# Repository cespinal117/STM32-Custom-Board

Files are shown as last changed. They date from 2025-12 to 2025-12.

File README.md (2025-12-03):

# STM32-Custom-Board

This is a board I decided to create to practice my PCB Design skills.  

I chose the STM32 as the main MCU due to me wanting to learn the STM32 platform.

My main motivation for the features of this board is that throughout college I mostly worked on projects involved Servo motors. Instead of having a separate Servo driver board with more wires, I thought it would be nice to have it all embedded into a single PCB that will power and control everything.  
The ESP32 was a last second addition as I thought it would be cool to be able to control the motors wirelessly through a web interface or bluetooth.

# Features
- STM32 MCU as the main processor
- ESP32 for wireless capabitlities
- PCA9685 Servo driver
- Switching between 5V USB or external 5V (prioritizes USB for the MCU if plugged in)

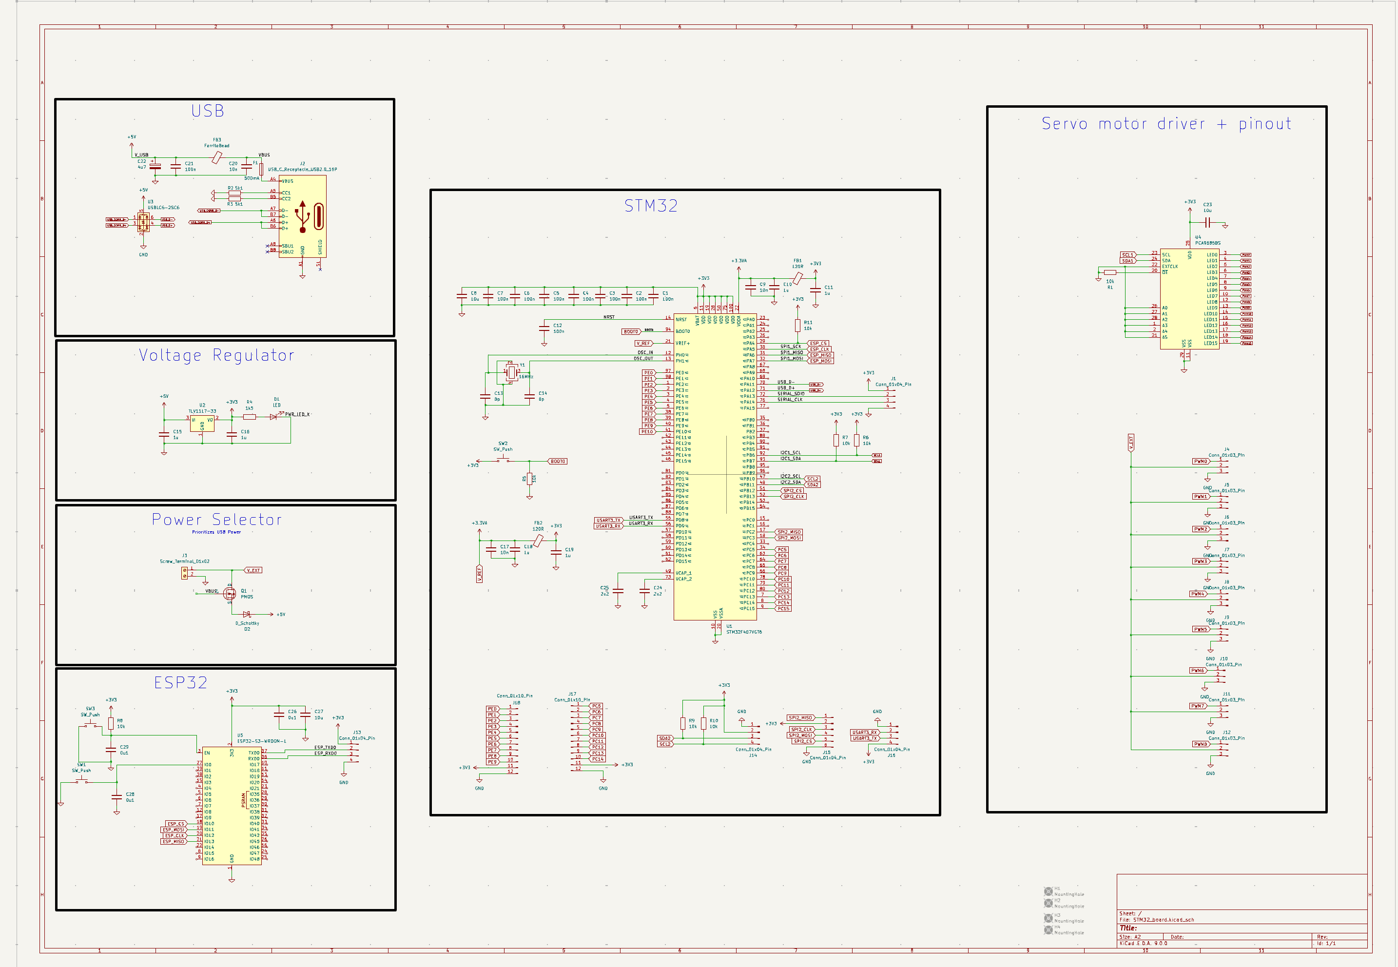
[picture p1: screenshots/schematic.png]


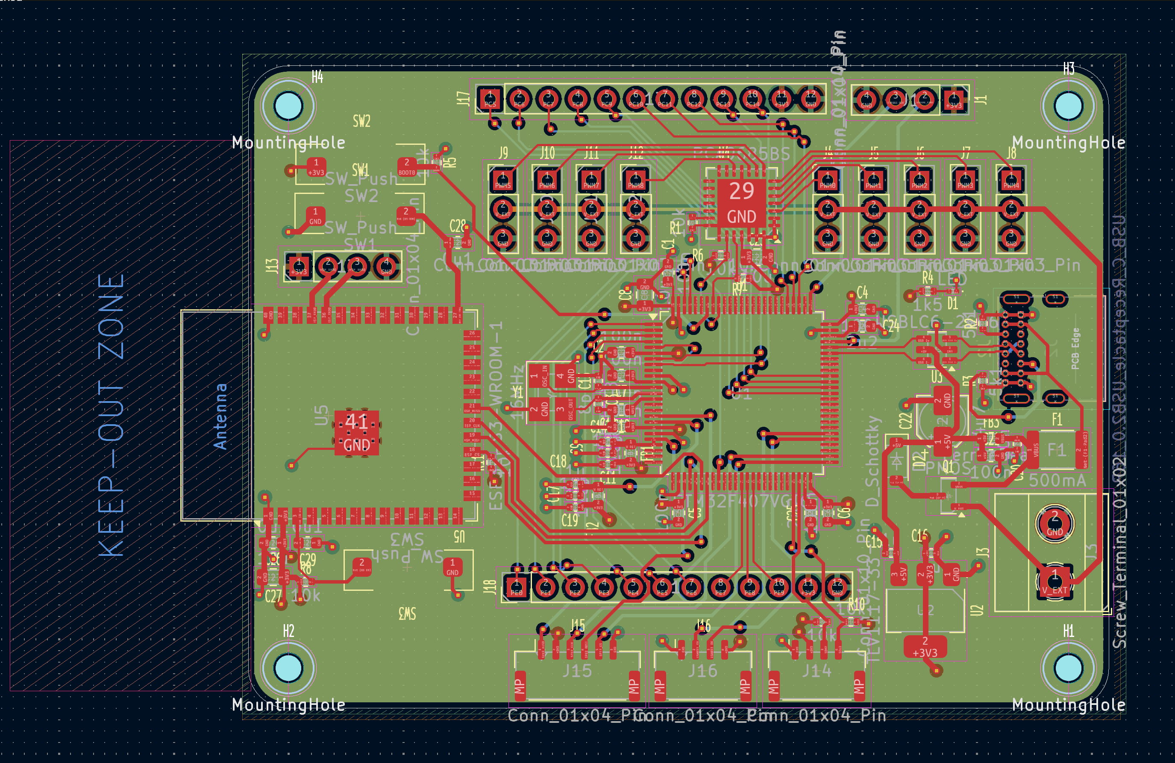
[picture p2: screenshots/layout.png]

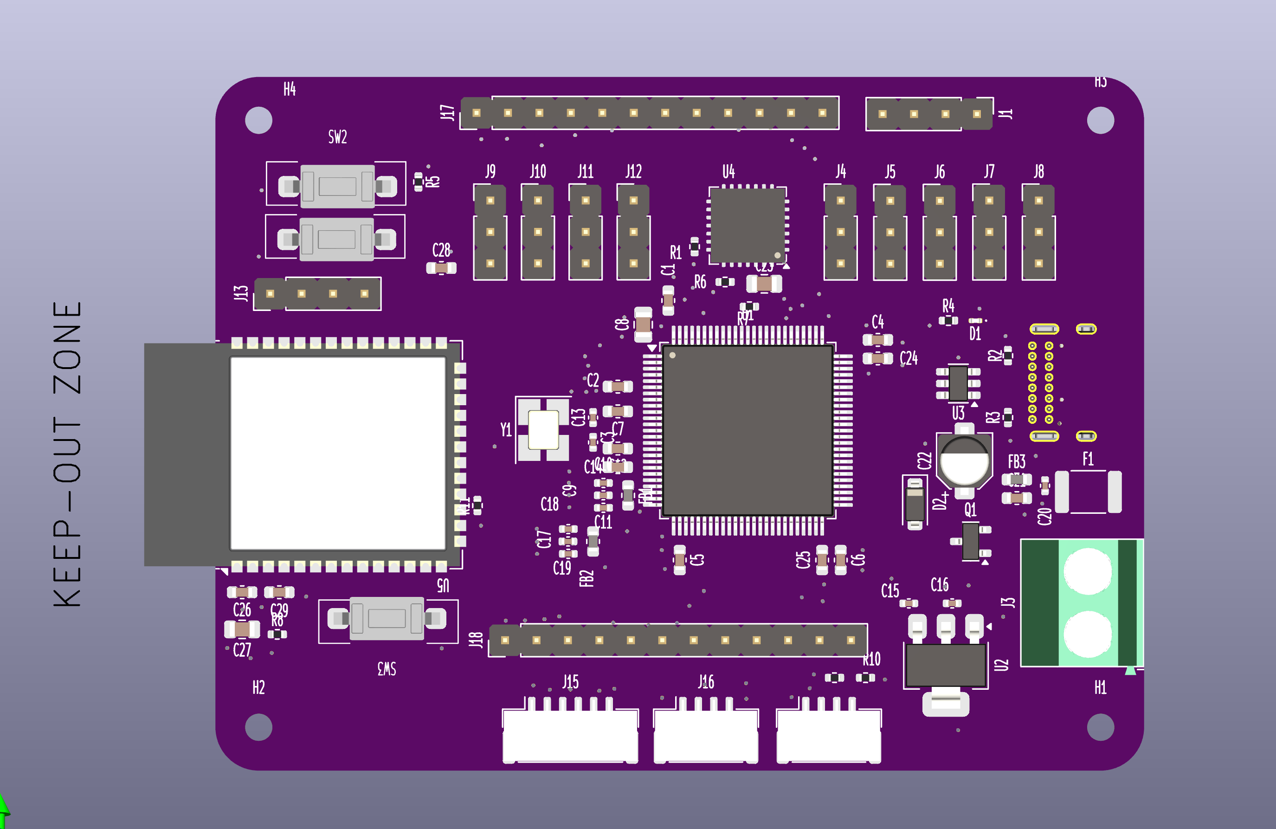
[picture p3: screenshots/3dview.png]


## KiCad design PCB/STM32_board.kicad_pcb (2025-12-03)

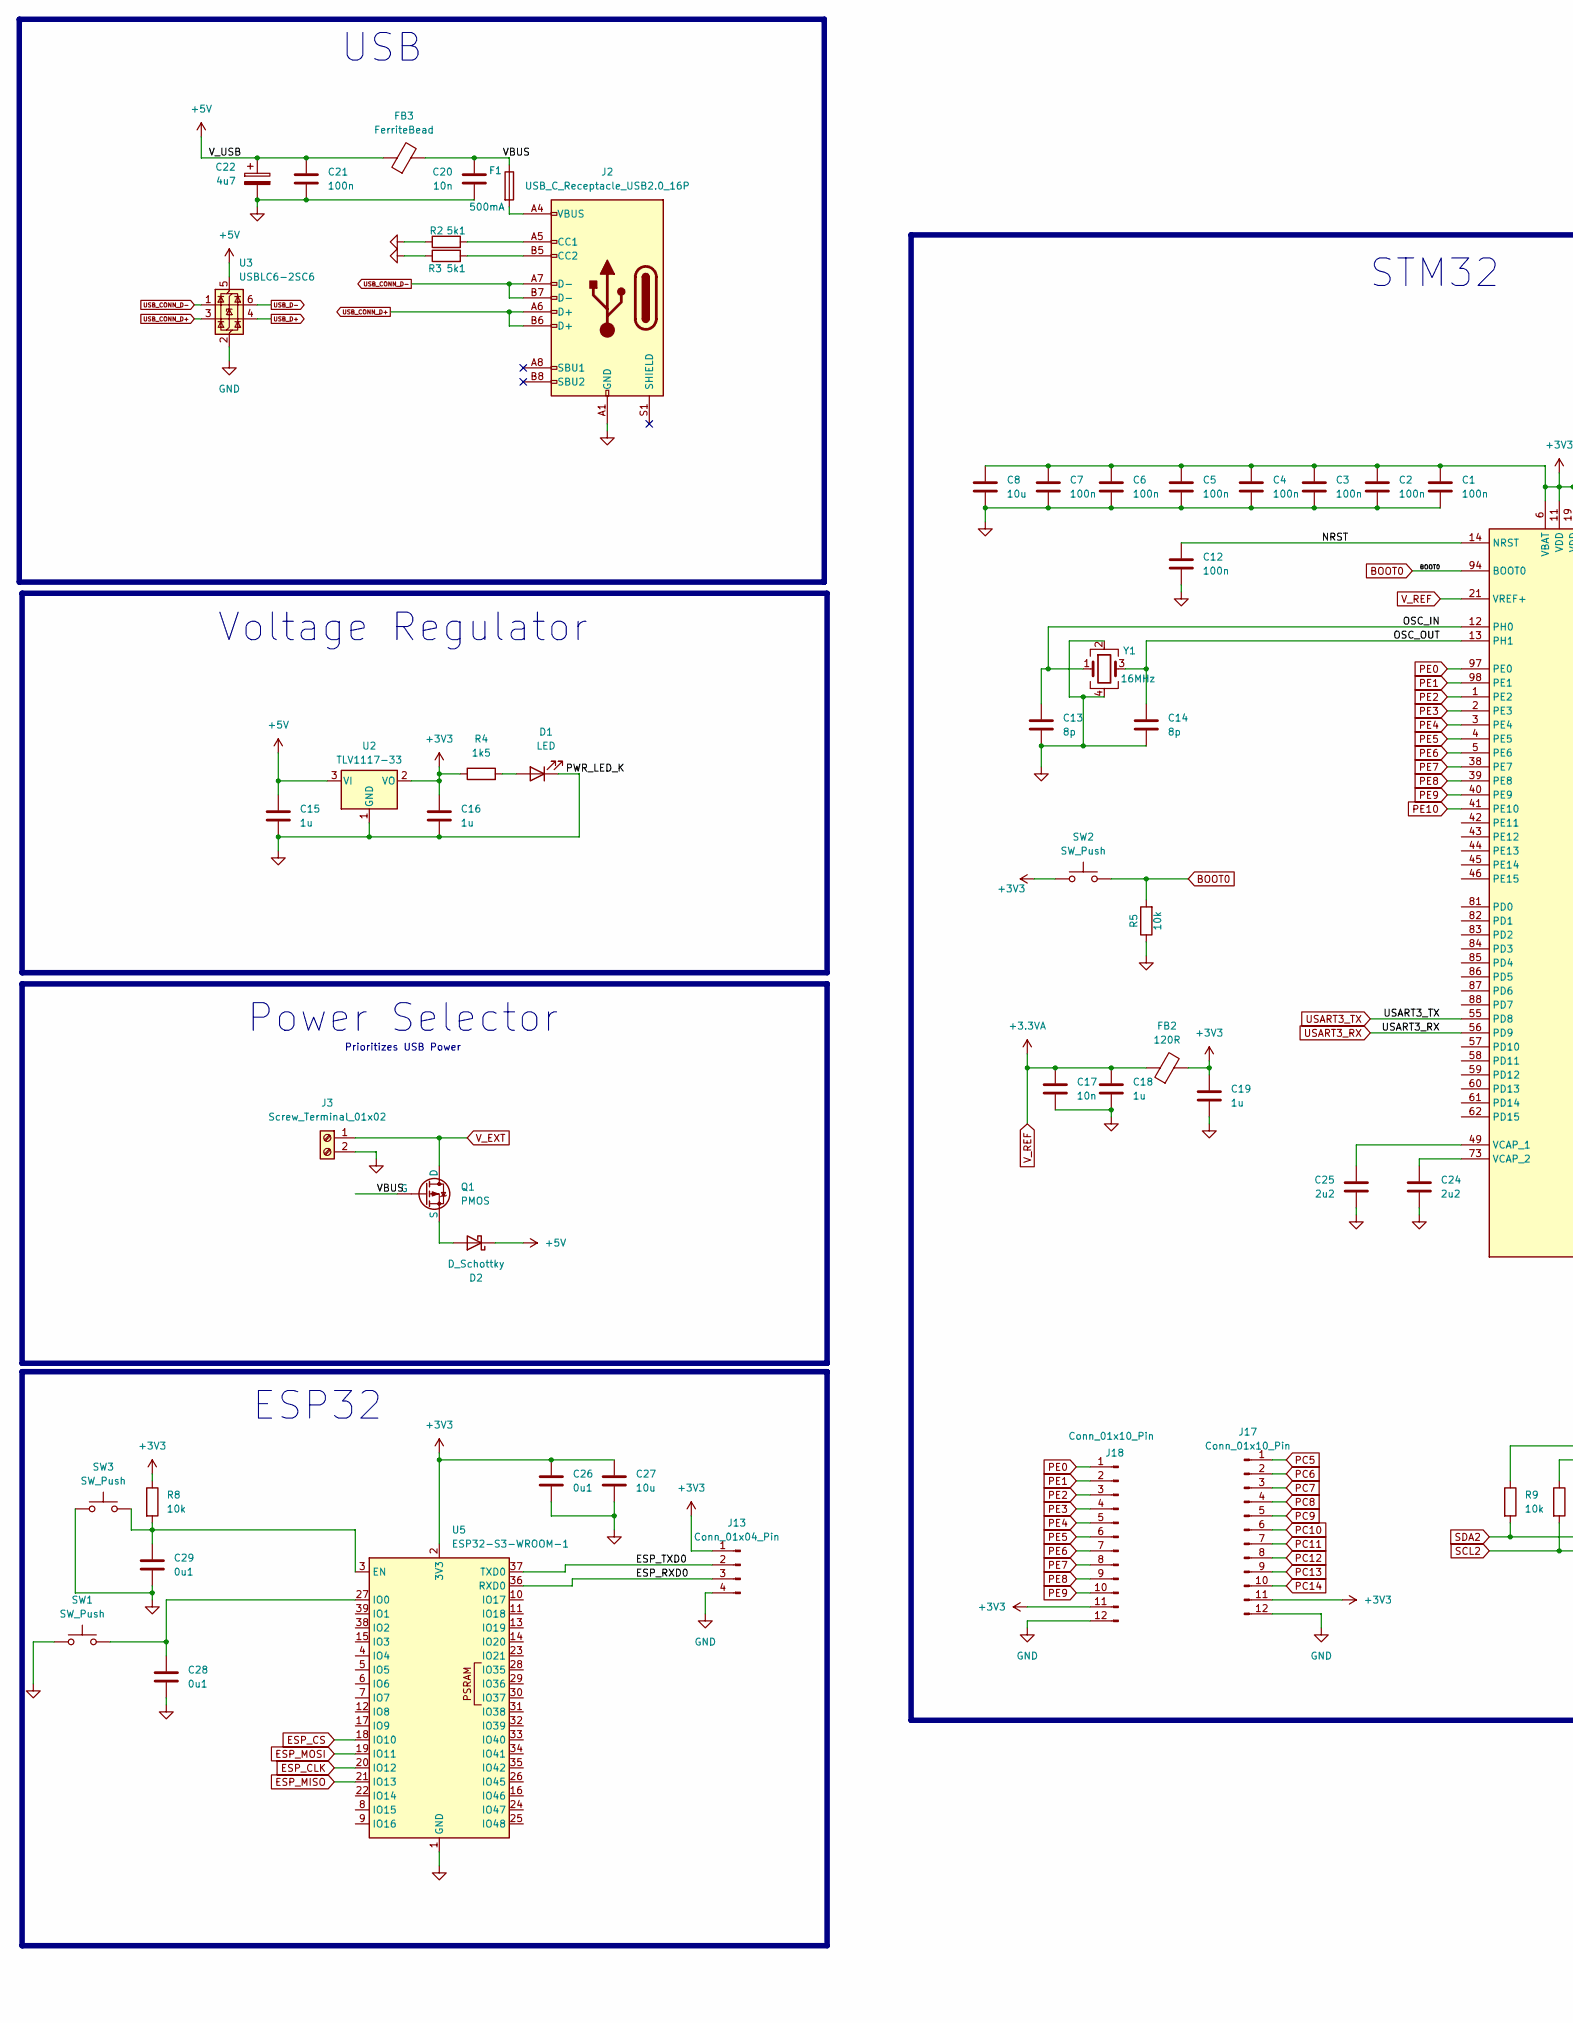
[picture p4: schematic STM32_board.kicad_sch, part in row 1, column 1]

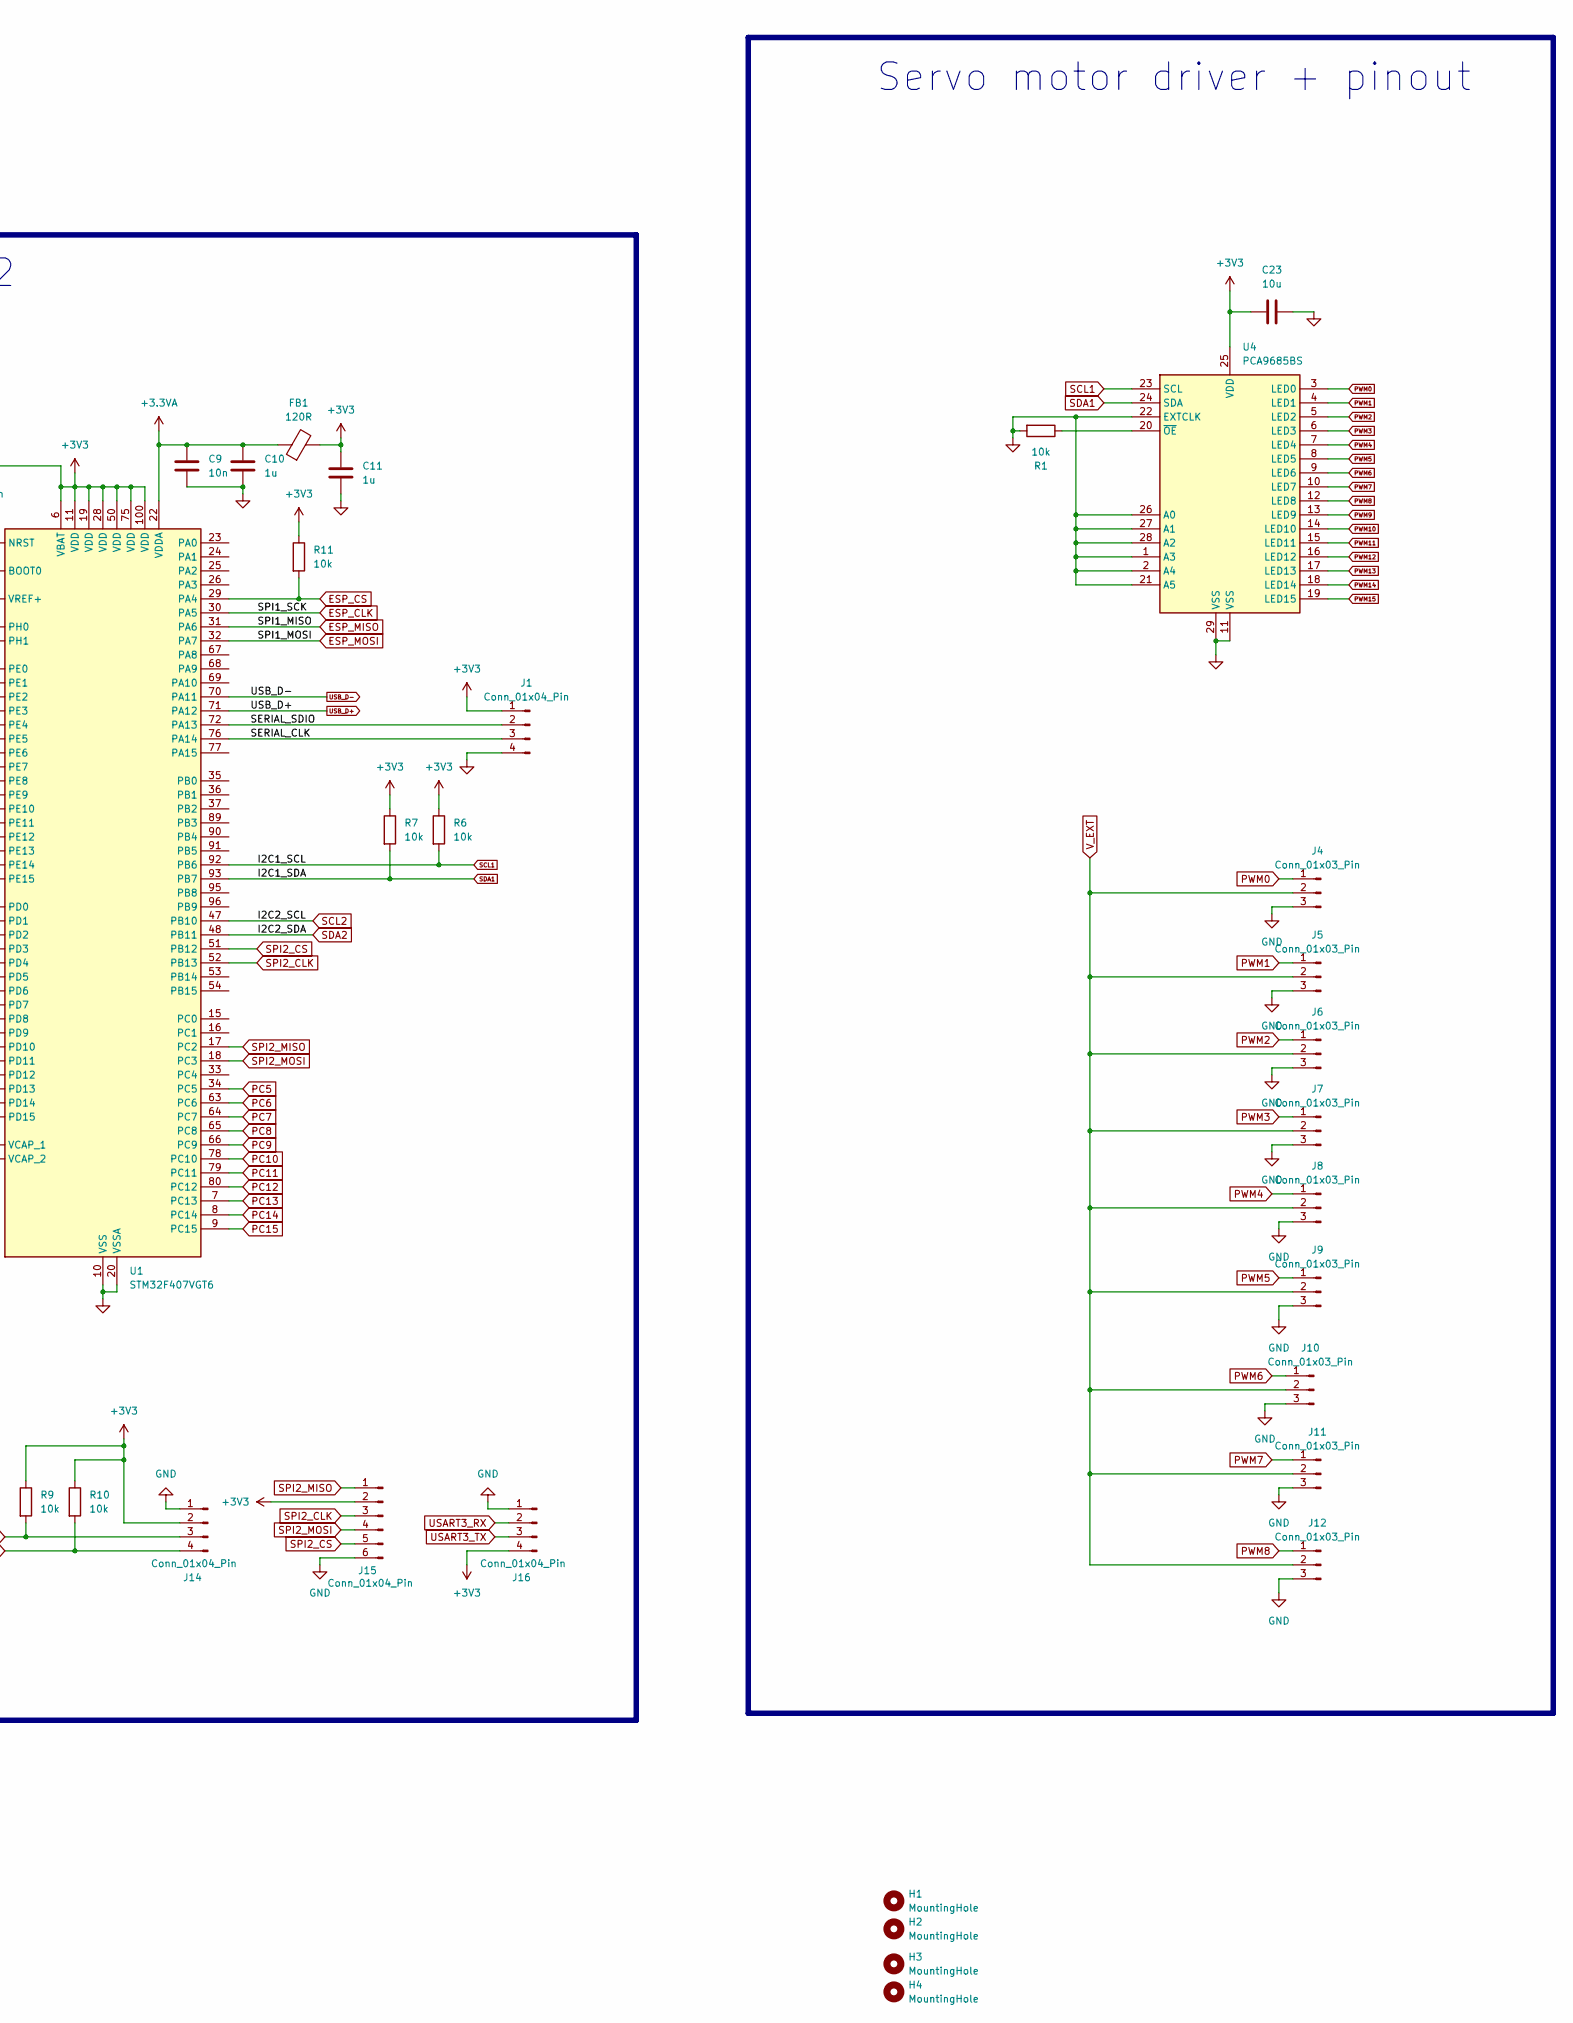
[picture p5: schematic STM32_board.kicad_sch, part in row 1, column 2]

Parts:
C1, C2, C3, C4, C5, C6, C7, C12, C21: 100n; C_0603_1608Metric; Part Number 1276-1000-2-ND
C8, C23, C27: 10u; C_0805_2012Metric; Part Number 1276-1096-2-ND
C9, C17, C20: 10n; C_0402_1005Metric; Part Number 1276-1028-2-ND
C10, C11, C15, C16, C18, C19: 1u; C_0402_1005Metric; Part Number 1276-1067-2-ND
C13, C14: 8p; C_0402_1005Metric; Part Number 1276-CL05C080DB51PNCTR-ND
C22: 4u7; CP_Elec_4x5.7; Part Number 732-8258-2-ND
C24, C25: 2u2; C_0603_1608Metric; Part Number 1276-1040-2-ND
C26, C28, C29: 0u1; C_0603_1608Metric; Part Number 1276-1000-2-ND
D1: LED; LED_0201_0603Metric; Part Number 160-1446-2-ND
D2: D_Schottky; D_SOD-123; Part Number 1N5819HW-FDITR-ND
F1: 500mA; Fuse_1812_4532Metric; Part Number MF-MSMF050-2TR-ND
FB1, FB2: 120R; L_0603_1608Metric; Part Number 490-3996-2-ND
FB3: FerriteBead; L_0603_1608Metric; Part Number 541-2604-2-ND
H1, H2, H3, H4: MountingHole; MountingHole_2.2mm_M2
J1, J13: Conn_01x04_Pin; PinHeader_1x04_P2.54mm_Vertical
J2: USB_C_Receptacle_USB2.0_16P; USB_C_Receptacle_GCT_USB4085; Part Number 2073-USB4085-GF-ATR-ND
J3: Screw_Terminal_01x02; TerminalBlock_Phoenix_MKDS-1,5-2-5.08_1x02_P5.08mm_Horizont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; Part Number 277-1247-ND
J4, J5, J6, J7, J8, J9, J10, J11, J12: Conn_01x03_Pin; PinHeader_1x03_P2.54mm_Vertical
J14, J16: Conn_01x04_Pin; JST_GH_SM04B-GHS-TB_1x04-1MP_P1.25mm_Horizontal; Part Number 455-1566-2-ND
J15: Conn_01x04_Pin; JST_GH_SM06B-GHS-TB_1x06-1MP_P1.25mm_Horizontal; Part Number 455-1568-2-ND
J17, J18: Conn_01x10_Pin; PinHeader_1x12_P2.54mm_Vertical
Q1: PMOS; SOT-23; Part Number SSM3J328RLFTR-ND
R1, R5, R6, R7, R8, R9, R10, R11: 10k; R_0402_1005Metric; Part Number 311-10.0KLRTR-ND
R2, R3: 5k1; R_0402_1005Metric; Part Number 311-5.10KLRTR-ND
R4: 1k5; R_0402_1005Metric; Part Number 311-1.50KLRTR-ND
SW1, SW2, SW3: SW_Push; PTS636 SM43 SMTR LFS; Part Number CKN12310-2-ND
U1: STM32F407VGT6; LQFP-100_14x14mm_P0.5mm; Part Number 497-11605-ND
U2: TLV1117-33; SOT-223-3_TabPin2; Part Number 296-28778-2-ND
U3: USBLC6-2SC6; SOT-23-6; Part Number 497-5235-2-ND
U4: PCA9685BS; QFN-28-1EP_6x6mm_P0.65mm_EP4.25x4.25mm; Part Number 568-5305-2-ND
U5: ESP32-S3-WROOM-1; Part Number 1965-ESP32-S3-WROOM-1-N8TR-ND
Y1: 16MHz; Crystal_SMD_3225-4Pin_3.2x2.5mm_HandSoldering; Part Number SER4069TR-ND

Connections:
+3V3: C1.1, C2.1, C3.1, C4.1, C5.1, C6.1, C7.1, C8.1, C11.1, C16.1, C19.1, C23.1, C26.1, C27.1, FB1.2, FB2.2, J1.1, J13.1, J14.2, J15.2, J16.4, J17.11, J18.11, R4.1, R6.1, R7.1, R8.1, R9.1, R10.1, R11.1, SW2.1, U1.6 (VBAT), U1.11 (VDD), U1.19 (VDD), U1.28 (VDD), U1.50 (VDD), U1.75 (VDD), U1.100 (VDD), U2.2 (VO), U4.25 (VDD), U5.2 (3V3)
+5V: C15.1, C21.1, C22.1, D2.1 (K), FB3.1, U2.3 (VI), U3.5 (VBUS)
/ESP_RXD0: J13.3, U5.36 (RXD0)
/ESP_TXD0: J13.2, U5.37 (TXD0)
/NRST: C12.1, U1.14 (NRST)
/OSC_IN: C13.1, U1.12 (PH0), Y1.1
/OSC_OUT: C14.1, U1.13 (PH1), Y1.3
/SERIAL_CLK: J1.3, U1.76 (PA14)
/SERIAL_SDIO: J1.2, U1.72 (PA13)
/VBUS: C20.1, F1.1, FB3.2, Q1.2 (G)
BOOT0: R5.2, SW2.2, U1.94 (BOOT0)
ESP_CLK: U1.30 (PA5), U5.20 (IO12)
ESP_CS: R11.2, U1.29 (PA4), U5.18 (IO10)
ESP_MISO: U1.31 (PA6), U5.21 (IO13)
ESP_MOSI: U1.32 (PA7), U5.19 (IO11)
GND: C1.2, C2.2, C3.2, C4.2, C5.2, C6.2, C7.2, C8.2, C9.2, C10.2, C11.2, C12.2, C13.2, C14.2, C15.2, C16.2, C17.2, C18.2, C19.2, C20.2, C21.2, C22.2, C23.2, C24.2, C25.2, C26.2, C27.2, C28.2, C29.1, D1.1 (K), J1.4, J2.A1 (GND), J2.A12 (GND), J2.B1 (GND), J2.B12 (GND), J3.2, J4.3, J5.3, J6.3, J7.3, J8.3, J9.3, J10.3, J11.3, J12.3, J13.4, J14.1, J15.6, J16.1, J17.12, J18.12, R1.2, R2.1, R3.1, R5.1, SW1.1, SW3.1, U1.10 (VSS), U1.20 (VSSA), U1.27 (VSS), U1.74 (VSS), U1.99 (VSS), U2.1 (GND), U3.2 (GND), U4.1 (A3), U4.2 (A4), U4.11 (VSS), U4.21 (A5), U4.22 (EXTCLK), U4.26 (A0), U4.27 (A1), U4.28 (A2), U4.29 (VSS), U5.1 (GND), U5.40 (GND), U5.41 (GND), Y1.2, Y1.4
unnamed: D1.2 (A), R4.2
unnamed: D2.2 (A), Q1.3 (S)
unnamed: F1.2, J2.A4 (VBUS), J2.A9 (VBUS), J2.B4 (VBUS), J2.B9 (VBUS)
unnamed: J2.A5 (CC1), R2.2
unnamed: J2.B5 (CC2), R3.2
unnamed: C25.1, U1.49 (VCAP_1)
unnamed: C24.1, U1.73 (VCAP_2)
unnamed: R1.1, U4.20 (~OE)
unnamed: C29.2, R8.2, SW3.2, U5.3 (EN)
unnamed: C28.1, SW1.2, U5.27 (IO0)
PC5: J17.1, U1.34 (PC5)
PC6: J17.2, U1.63 (PC6)
PC7: J17.3, U1.64 (PC7)
PC8: J17.4, U1.65 (PC8)
PC9: J17.5, U1.66 (PC9)
PC10: J17.6, U1.78 (PC10)
PC11: J17.7, U1.79 (PC11)
PC12: J17.8, U1.80 (PC12)
PC13: J17.9, U1.7 (PC13)
PC14: J17.10, U1.8 (PC14)
PC15: U1.9 (PC15)
PE0: J18.1, U1.97 (PE0)
PE1: J18.2, U1.98 (PE1)
PE2: J18.3, U1.1 (PE2)
PE3: J18.4, U1.2 (PE3)
PE4: J18.5, U1.3 (PE4)
PE5: J18.6, U1.4 (PE5)
PE6: J18.7, U1.5 (PE6)
PE7: J18.8, U1.38 (PE7)
PE8: J18.9, U1.39 (PE8)
PE9: J18.10, U1.40 (PE9)
PE10: U1.41 (PE10)
PWM0: J4.1, U4.3 (LED0)
PWM1: J5.1, U4.4 (LED1)
PWM2: J6.1, U4.5 (LED2)
PWM3: J7.1, U4.6 (LED3)
PWM4: J8.1, U4.7 (LED4)
PWM5: J9.1, U4.8 (LED5)
PWM6: J10.1, U4.9 (LED6)
PWM7: J11.1, U4.10 (LED7)
PWM8: J12.1, U4.12 (LED8)
PWM9: U4.13 (LED9)
PWM10: U4.14 (LED10)
PWM11: U4.15 (LED11)
PWM12: U4.16 (LED12)
PWM13: U4.17 (LED13)
PWM14: U4.18 (LED14)
PWM15: U4.19 (LED15)
SCL1: R6.2, U1.92 (PB6), U4.23 (SCL)
SCL2: J14.4, R10.2, U1.47 (PB10)
SDA1: R7.2, U1.93 (PB7), U4.24 (SDA)
SDA2: J14.3, R9.2, U1.48 (PB11)
SPI2_CLK: J15.3, U1.52 (PB13)
SPI2_CS: J15.5, U1.51 (PB12)
SPI2_MISO: J15.1, U1.17 (PC2)
SPI2_MOSI: J15.4, U1.18 (PC3)
USART3_RX: J16.2, U1.56 (PD9)
USART3_TX: J16.3, U1.55 (PD8)
USB_CONN_D+: J2.A6 (D+), J2.B6 (D+), U3.3 (I/O2)
USB_CONN_D-: J2.A7 (D-), J2.B7 (D-), U3.1 (I/O1)
USB_D+: U1.71 (PA12), U3.4 (I/O2)
USB_D-: U1.70 (PA11), U3.6 (I/O1)
V_EXT: J3.1, J4.2, J5.2, J6.2, J7.2, J8.2, J9.2, J10.2, J11.2, J12.2, Q1.1 (D)
V_REF: C9.1, C10.1, C17.1, C18.1, FB1.1, FB2.1, U1.21 (VREF+), U1.22 (VDDA)

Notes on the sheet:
ESP32
STM32
Servo motor driver + pinout
Power Selector
Voltage Regulator
Prioritizes USB Power
USB

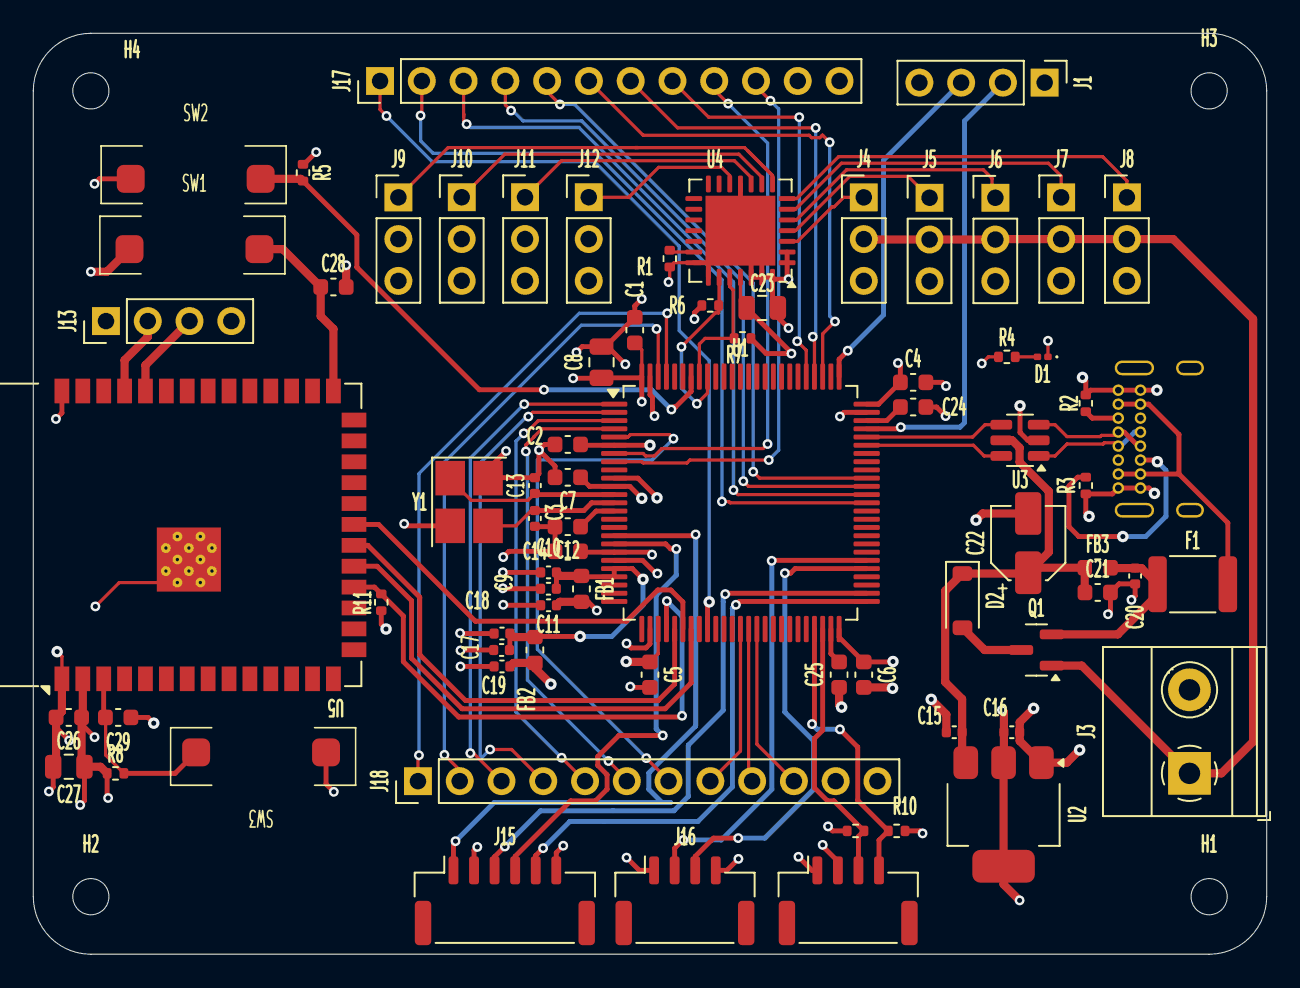
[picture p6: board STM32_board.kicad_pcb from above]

Board: 4 copper layers, 75.0 x 56.0 mm, 78 parts (1 on the bottom side), 71 nets.
